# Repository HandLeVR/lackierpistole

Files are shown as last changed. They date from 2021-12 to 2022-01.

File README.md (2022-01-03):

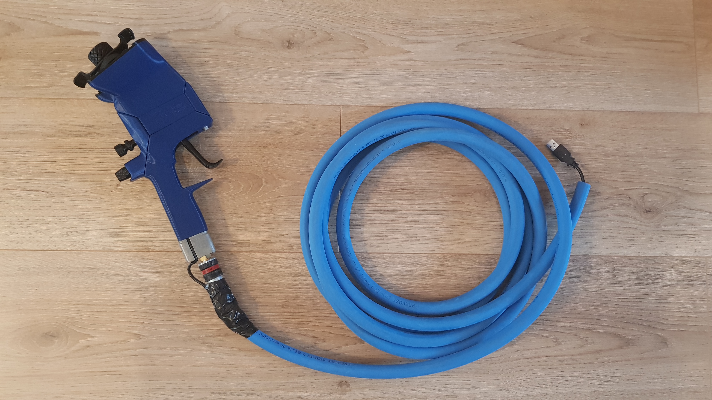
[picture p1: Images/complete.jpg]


In diesem Repository sind die 3D-Modelle sowie Anleitungen enthalten, die den Druck und den Zusammenbau einer Nachbildung einer echten Lackierpistole ermöglichen.

# Voraussetzungen
- 3D-Drucker
- Lötkolben
- Verschiedenfarbige dünne Kabel
- Schrumpfschläuche/Isolierband

Weitere benötigte Materialien sind im Dokument [BenötigteMaterialien.pdf](Anleitung/BenötigteMaterialien.pdf) aufgelistet.

# Dateistruktur

**Anleitung**: Anleitung für den Zusammenbau der Lackierpistole. Dabei wird auch beschrieben, wie die Elektronik verlötet werden muss und wie die Software auf dem Arduino Nano installiert wird.

**Druckdateien**: Die 3D-Modelle der Einzelteile der Lackierpistole, die für den Nachbau gedruckt werden müssen.

**Sketch**: Die Software, die auf dem Arduino Nano installiert werden muss.

# Druckschlauch

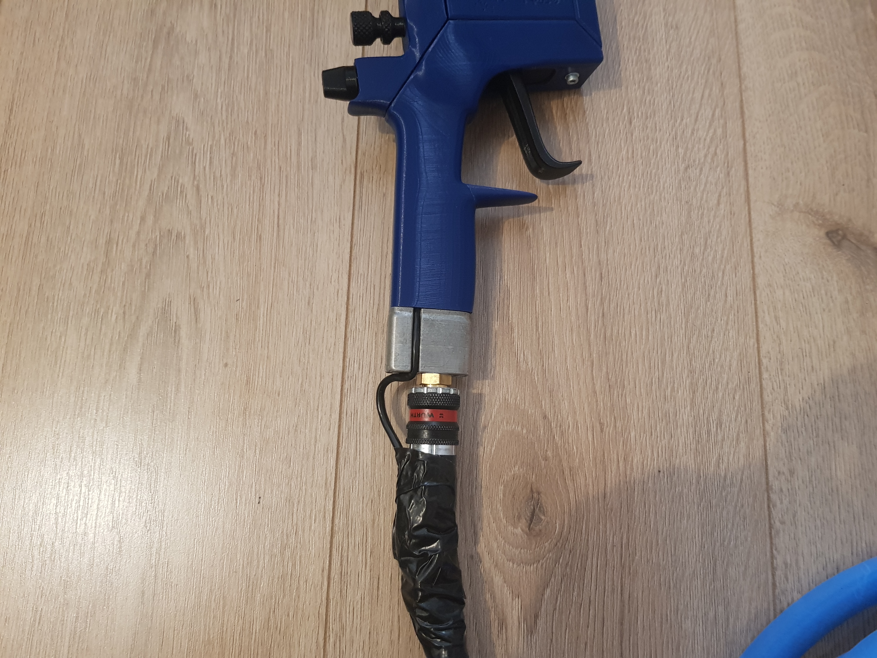
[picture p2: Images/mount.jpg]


Für eine besserer Haptik sollte ein Druckschlauch an dem Nachbau befestigt werden. Hierfür kann ein normaler Druckschlauch verwendet werden. Auf den Bildern ist ein 5 Meter langer PVC-Schlauch mit einem Innendurchmesser von 9 mm zu sehen. Soll das USB-Kabel durch den Schlauch geführt werden, sollte dieser mindestens einen Durchmesser von 9 mm haben. Zur Befestigung des Schlauches kann ein Kupplungsstecker mit Außengewinde (golden auf dem Bild) genutzt werden, der in die Druckschlauchhalterung (`Druckdateien\Druckschlauchmount\Schraubmount.3mf`) gedreht wird. Auf dem Bild ist die Druckschlauchhalterung metallisch und sollte wenn möglich auch beim eigenen Druck aus Metall bestehen.

Um das USB-Kabel durch den Schlauch zu führen, wurde dieser am Ende, das zur Lackierpistole führt, aufgeschnitten. Das Ventil am anderen Ende wurde abgeschnitten, um von hier das Kabel durch den Schlauch zu führen. In die Lackierpistole muss der USB-Mini-Stecker, weshalb dieser voran durch den Schlauch geschoben wird. In der Regel muss etwas von dem Gummi des Steckers entfernt werden, damit der Stecker durch den Schlauch passt. Der Stecker wird dann durch die aufgeschnittene Stelle am anderen Ende geführt und in die Lackierpistole gesteckt. Das schwarze Klebeband dient zur Stabilisierung.

# Treiber

Möglicherweise ist ein Treiber nötig, damit der Arduino Nano vom PC erkannt wird. Dieser kann [hier](http://www.wch-ic.com/downloads/CH341SER_ZIP.html) heruntergeladen werden.

# Lackierpistole initialisieren

Um die Lackierpistole in der VR-Lackierwerkstatt nutzen zu können, müssen die Position der Lackierpistole, der Abzugshebel und die Drehknöpfe initialisiert werden. Dies muss in der Regel nur einmal gemacht werden oder wenn sich die Position des Controllers an der Lackierpistole verändert. Der Initialisierungsprozess wird im Probiermodus der VR-Lackierwerkstatt durchgeführt. Dieser kann gestartet werden, wenn im Anmeldebildschirm *Ohne Anmeldung* oder im Hauptmenü *Probiermodus* ausgewählt wird.

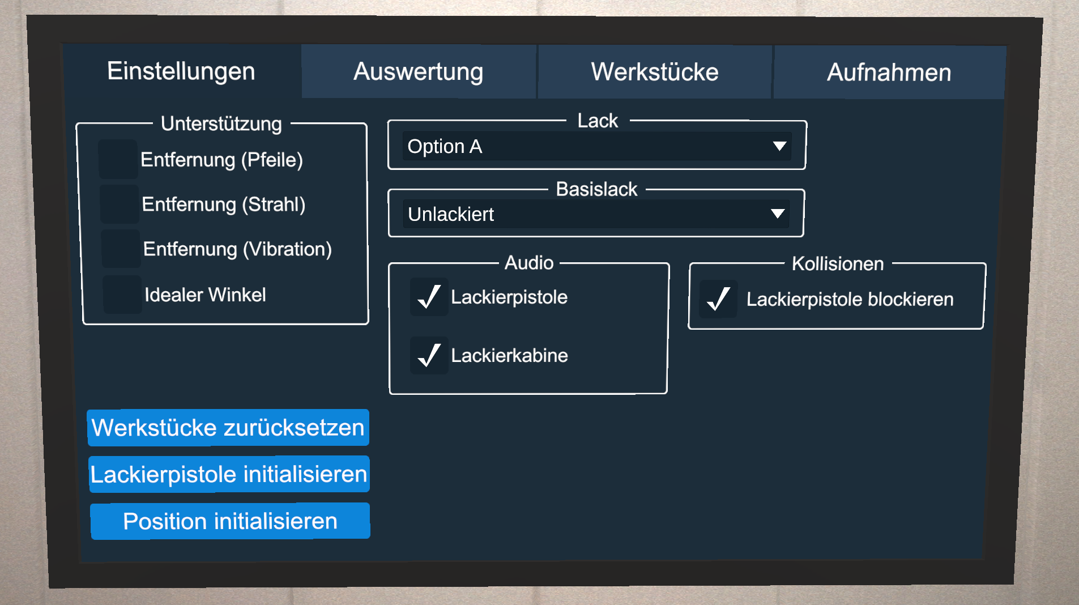
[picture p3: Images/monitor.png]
.

## Abzugshebel und Drehknöpfe initialisieren

Die Initialisierung des Abzugshebels und der Drehknöpfe kann gestartet werden, indem *Lackierpistole initialisieren* auf dem Monitor ausgewählt  oder die Taste "I" auf der Tastatur gedrückt wird. Auf dem Monitor erscheinen dann Anweisungen, die durchgeführt werden müssen.

## Position
Die Initialisierung der Position der Lackierpistole kann gestartet werden, indem *Position initialisieren* auf dem Monitor ausgewählt oder die Taste "O" auf der Tastatur gedrückt wird. Vor dem Monitor erscheint dann eine durchsichtige Lackierpistole und die virtuelle Lackierpistole in der Hand verschwindet. Nun muss die echte Lackierpistole möglichst genau so vor dem Monitor positioniert werden, dass diese mit der durchsichtigen Lackierpistole übereinstimmt. Der Prozess wird beendet, wenn der Abzughebel gedrückt wird.

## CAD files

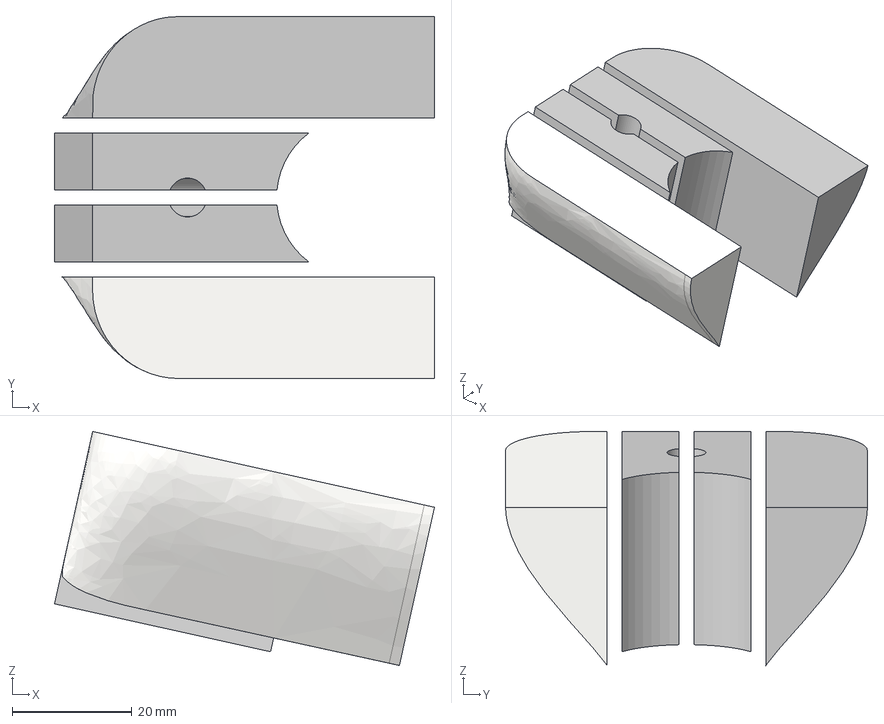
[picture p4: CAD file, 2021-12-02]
Druckdateien/Aufnahme/Gewicht.step
63.5 x 60.5 x 39.1 mm

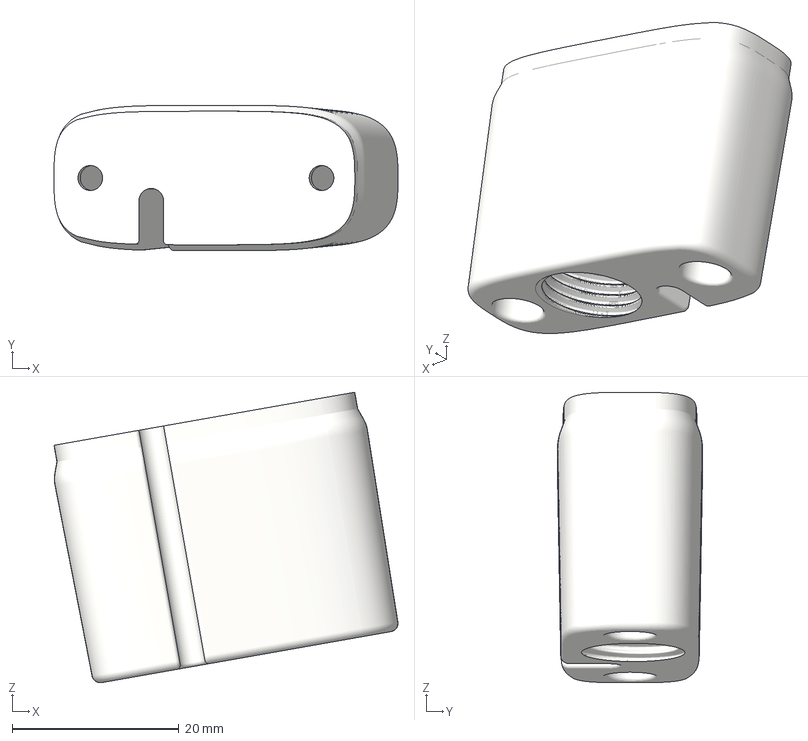
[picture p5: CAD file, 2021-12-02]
Druckdateien/Druckschlauchmount/Schraubmount.3mf
41.2 x 17.4 x 34.8 mm

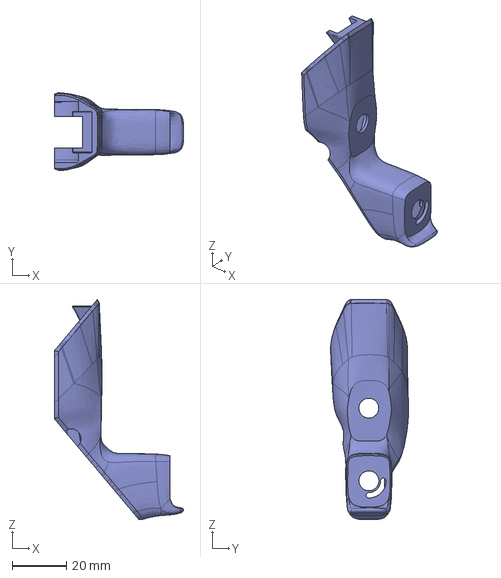
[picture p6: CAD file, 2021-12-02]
Druckdateien/Gehäuse/gehäuse hinten.step
47.6 x 28.6 x 80.9 mm

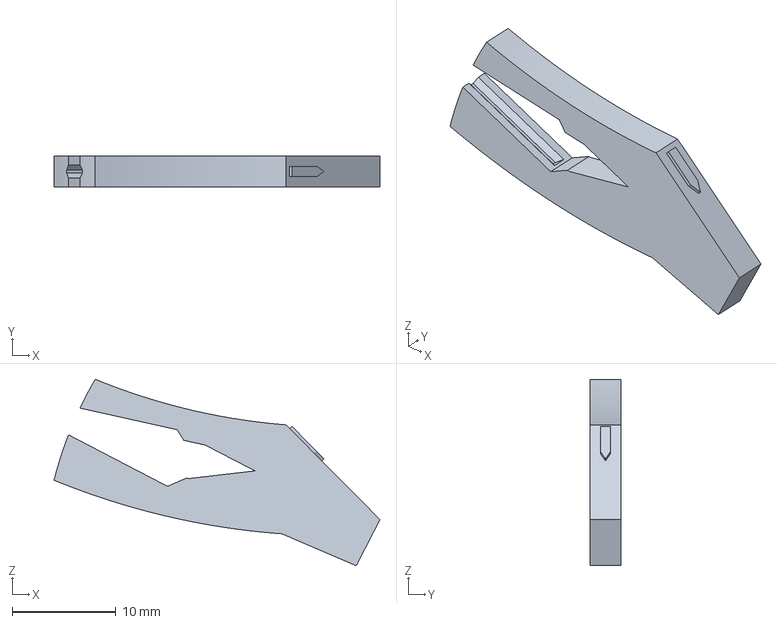
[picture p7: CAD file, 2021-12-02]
Druckdateien/Mechanik/Abzug_greifer.3mf
31.4 x 3.00 x 18.0 mm

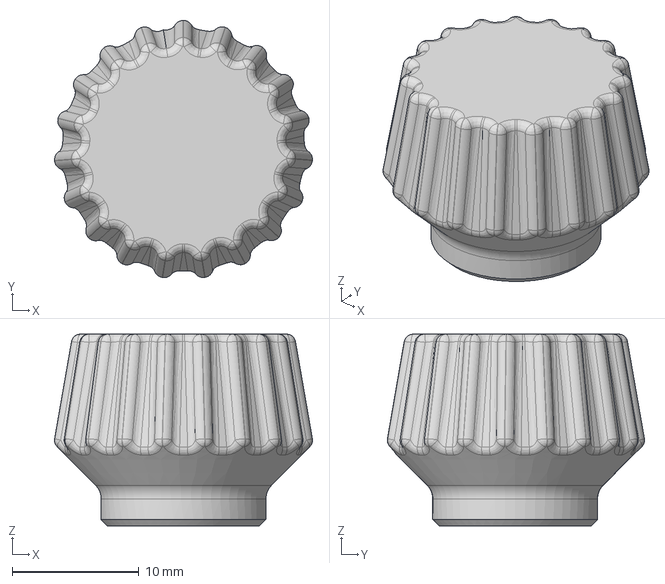
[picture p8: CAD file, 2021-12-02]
Druckdateien/Regler/Seitenregler.step
20.3 x 20.3 x 15.1 mm

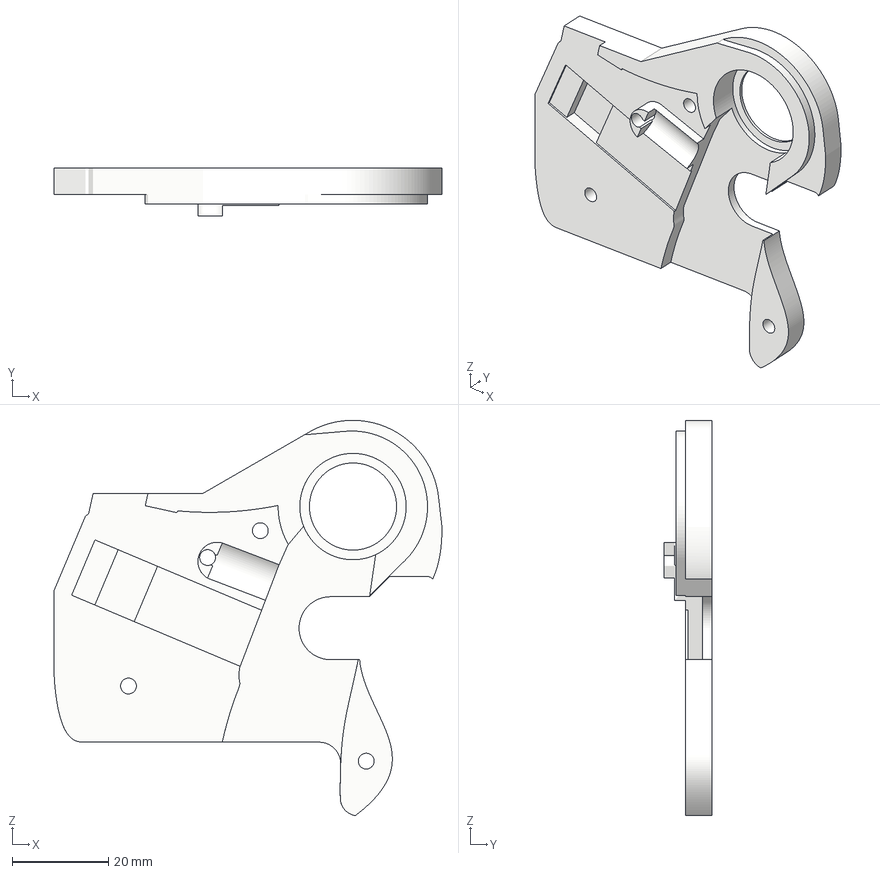
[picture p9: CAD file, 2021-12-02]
Druckdateien/Träger/Trägerkappe_rechts.3mf
80.8 x 10.0 x 82.3 mm

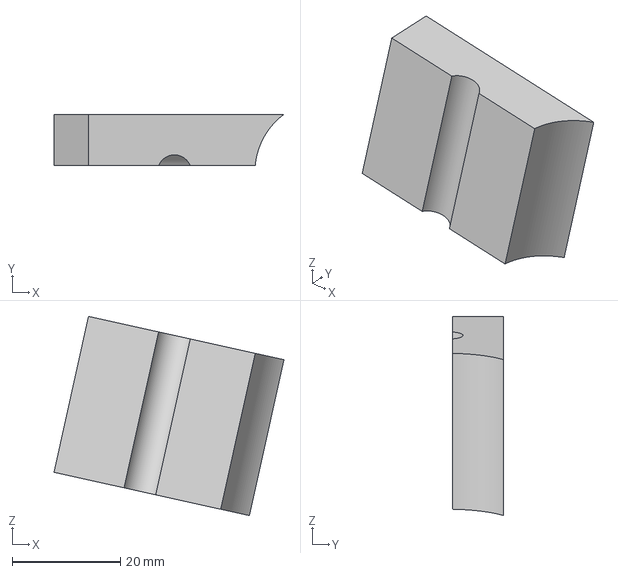
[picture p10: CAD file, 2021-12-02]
Druckdateien/Aufnahme/gewicht rr.3mf
42.5 x 9.50 x 36.8 mm

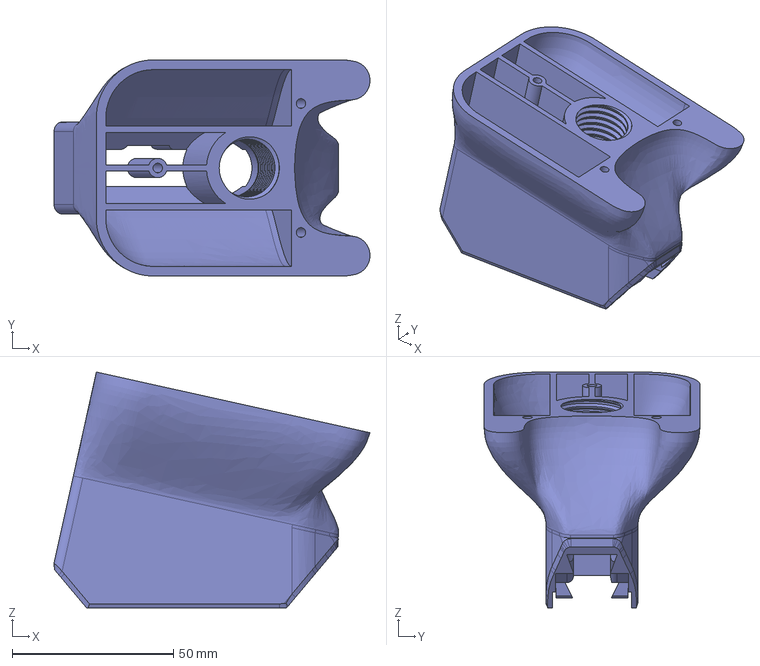
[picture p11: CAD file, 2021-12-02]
Druckdateien/Gehäuse/gehäuse oben.step
98.0 x 67.0 x 73.2 mm

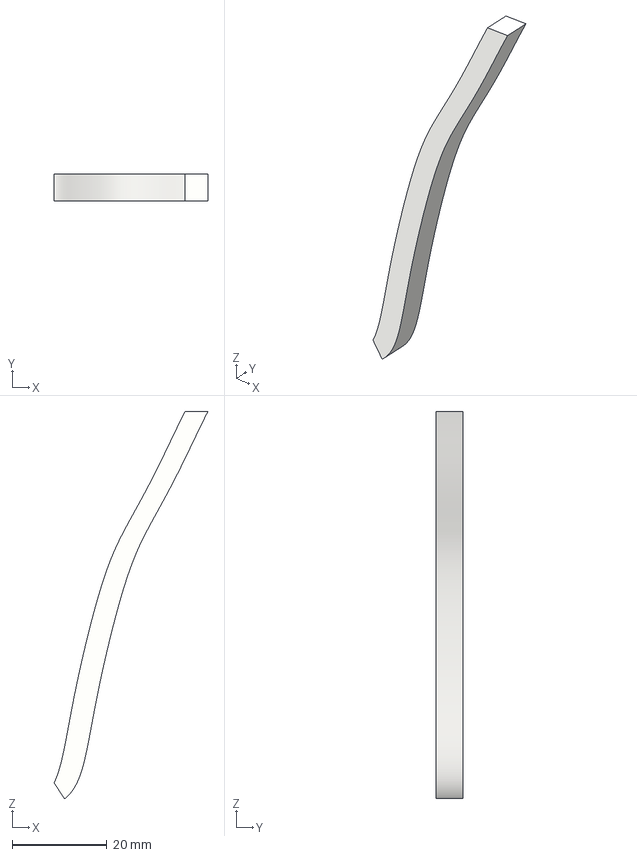
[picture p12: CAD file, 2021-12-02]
Druckdateien/Mechanik/Abzug_inlay.3mf
32.5 x 5.70 x 81.8 mm

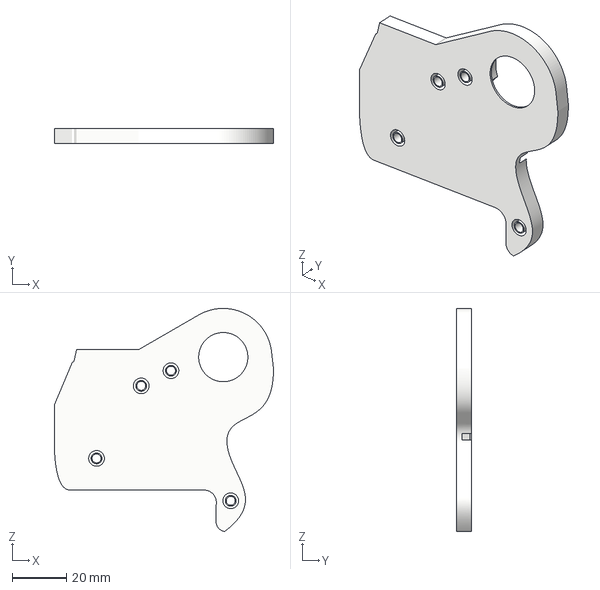
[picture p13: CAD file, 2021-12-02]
Druckdateien/Träger/Trägerkappe_links.3mf
80.8 x 5.50 x 82.3 mm

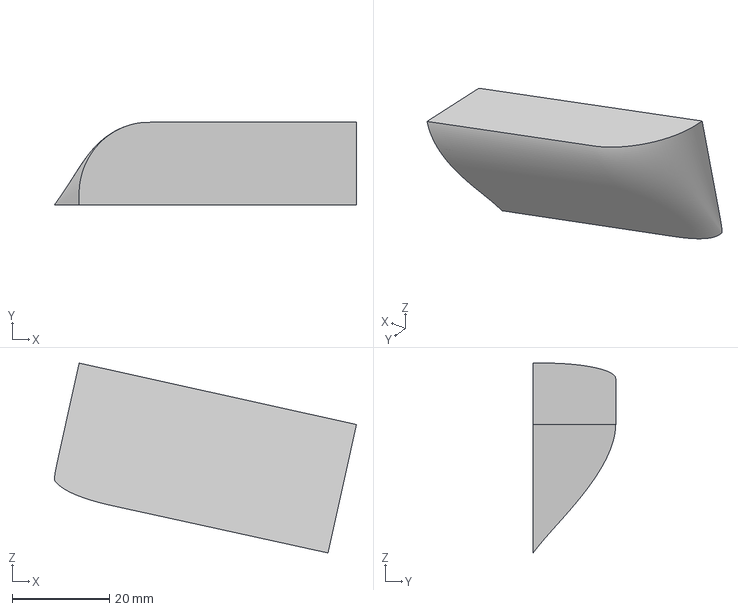
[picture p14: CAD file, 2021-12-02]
Druckdateien/Aufnahme/gewicht Rechts.3mf
62.2 x 17.0 x 39.1 mm

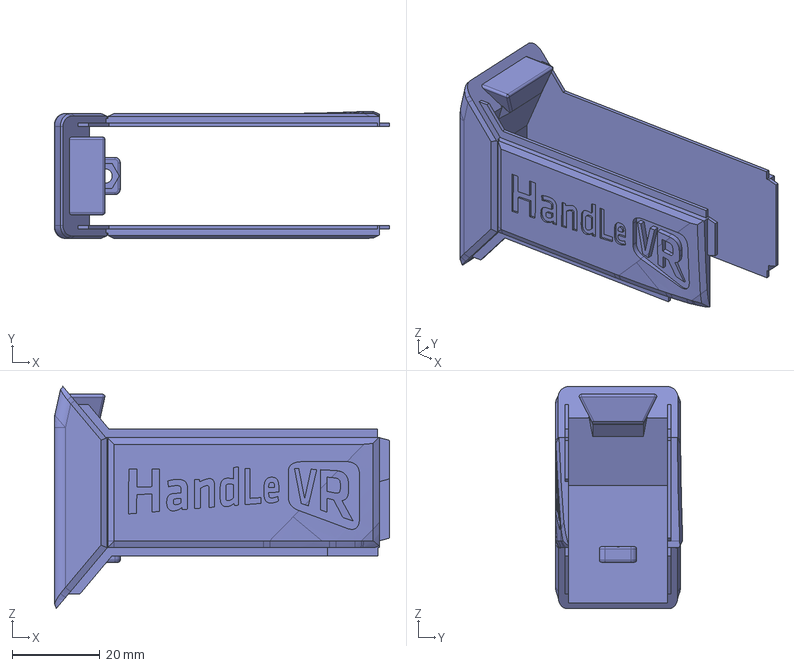
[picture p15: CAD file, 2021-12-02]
Druckdateien/Gehäuse/gehäuse vorne.step
76.4 x 28.9 x 50.6 mm

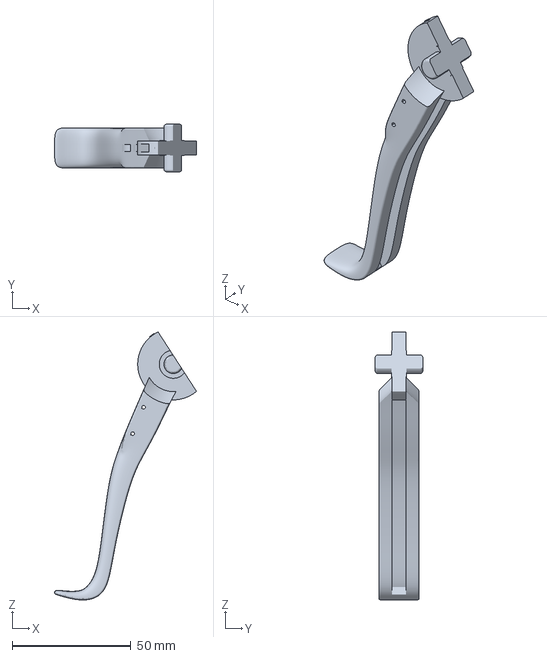
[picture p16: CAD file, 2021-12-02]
Druckdateien/Mechanik/Abzug.3mf
59.8 x 20.0 x 112.8 mm

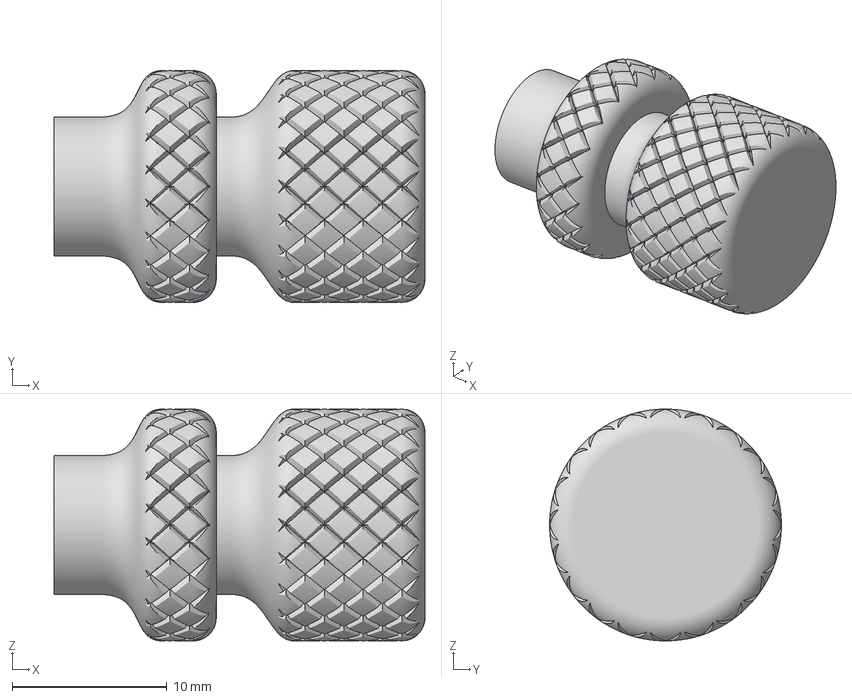
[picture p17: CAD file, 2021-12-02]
Druckdateien/Regler/Regler_HiOb.3mf
24.0 x 15.0 x 15.0 mm

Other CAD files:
Druckdateien/Druckschlauchmount/Schraubanschluss.step
Druckdateien/Regler/Regler_Seite.3mf
Druckdateien/Träger/träger.step
Druckdateien/Aufnahme/gewicht ll.3mf
Druckdateien/Aufnahme/Auflageplatte v4.step
Druckdateien/Aufnahme/Auflageplatte.3mf
Druckdateien/Aufnahme/Klemme.3mf
Druckdateien/Aufnahme/Schraube.3mf
Druckdateien/Aufnahme/Schraube.step
Druckdateien/Aufnahme/gewicht links.3mf
Druckdateien/Aufnahme/klemme v5.step
Druckdateien/Gehäuse/Gehäuse Hinten.3mf
Druckdateien/Gehäuse/Gehäuse vorne.3mf
Druckdateien/Gehäuse/Nase.3mf
Druckdateien/Gehäuse/Nasenzapfen.3mf
Druckdateien/Gehäuse/gehäuse Oben.3mf
Druckdateien/Gehäuse/gehäuse unten.step
Druckdateien/Gehäuse/gehäuse_unten.3mf
Druckdateien/Mechanik/Abzug v3.step
Druckdateien/Mechanik/Federhülse.3mf
Druckdateien/Mechanik/federhülse.step
Druckdateien/Regler/Regler_HiUn.3mf
Druckdateien/Regler/Regler_HiUn.step
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

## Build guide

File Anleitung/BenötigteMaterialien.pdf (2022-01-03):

Artikel | technische Bez. | Menge | Lospreis | Losmenge | Bemerkung
PLA | PLA | 260 g | 16,00 € | 320 g | Preislich stark optimierbar, bei uns 60€/2kg
Zinn | SN95SB4CU1 | 380 g | 27,90 € | 500 g | SN99,9/SN96AG4/… möglichst ohne Blei (Pb) -> RoHS
Kugellager | 608zz | 2 Stk | 9,99 € | 20 Stk
Feder | Z-095I | 1 Stk | 2,70 € | 1 Stk | schnell hohe Rabatte
Feder | RZ-095I | 1 Stk | 2,83 € | 1 Stk | schnell hohe Rabatte
Arduino | Arduino Nano | 1 Stk | 4,60 € | 1 Stk
Drehpotentiometer | P0915N-FC15BR10K | 3 Stk | 1,38 € | 1 Stk
Schiebepotentiometer | PTA2043-2015DPB103 | 1 Stk | 1,31 € | 1 Stk
Druckluftanschluss | NW 7,2 Stecknippel | 5 Stk | 2,00 € | 1 Stk
Schrauben für Arduino | M1x3 | 4 Stk | | | gedruckte Klemme möglich, einzeln nicht kaufbar
Schrauben | M3x16 Zylinderkopf | 5 Stk | 0,06 € | 1 Stk | Mischpreis 0,04€ bis 0,08€, oft auch als Kiloware
Schrauben | M3x25 Zylinderkopf | 1 Stk | 0,06 € | 1 Stk
Schrauben | M3x45 Zylinderkopf | 2 Stk | 0,06 € | 1 Stk
Schrauben | M3x40 Zylinderkopf | 3 Stk | 0,06 € | 1 Stk
Schrauben | M3x20 Linsenkopf | 4 Stk | 0,06 € | 1 Stk
Mutter | M3 Mutter | 6 Stk | 0,06 € | 1 Stk
Unterlegschreibe | M3 Unterlegscheibe | 3 Stk | 0,06 € | 1 Stk
Drahtnägel | 1,2 mm Druckmesser | 4 Stk

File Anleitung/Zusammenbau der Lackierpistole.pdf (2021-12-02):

Jan Philipp Seeland | November, 2019

### HandLeVR Dokumentation Zusammenbau der Sensorik im 3D Druck der Lackierpistole

Die Sensorik im inneren des Controllers sorgt dafür, dass die Bewegung am Abzug und die Position der Einstellschrauben in der HandLeVR Software rekonstruiert werden können. Grundlegende Lötkenntnisse werden für den Zusammenbau vorausgesetzt.

Zum Zusammenbau der Sensorik wird folgendes benötigt:

- Lötkolben
- 3D Modell der Lackierpistole (Kern mit Schrauben und Kugellager)
- Verschiedenfarbige dünne Kabel
- Schrumpfschläuche/Isolierband
- 3x Drehpotentiometern
- 1x Schiebepotentiometer
- 1x Arduino Nano (ohne angelötete Pins)

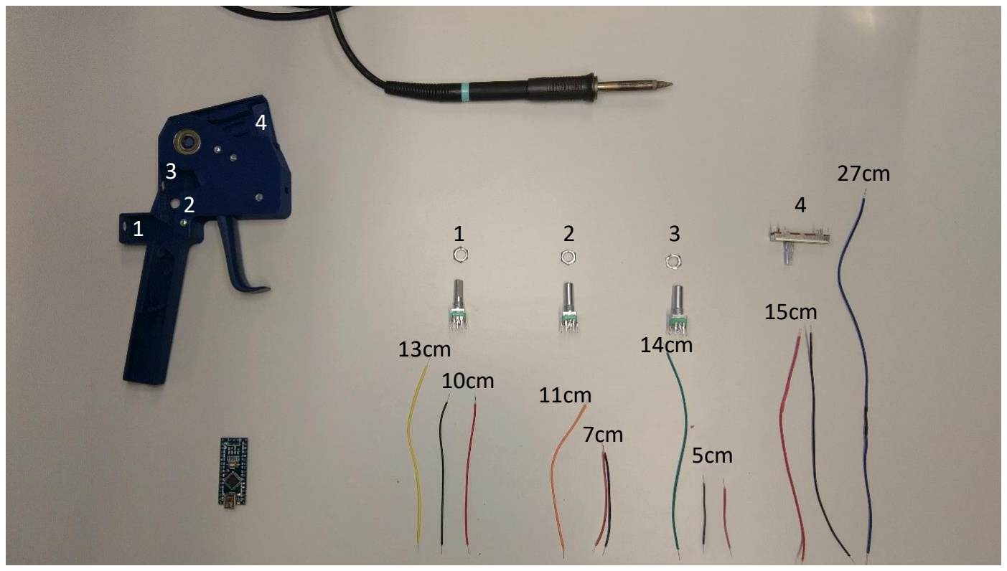
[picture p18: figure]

Die im Bild markierten Längen sind lediglich Empfehlungen! Es ist genug Stauraum im Griff der Pistole für überschüssige Kabellänge.

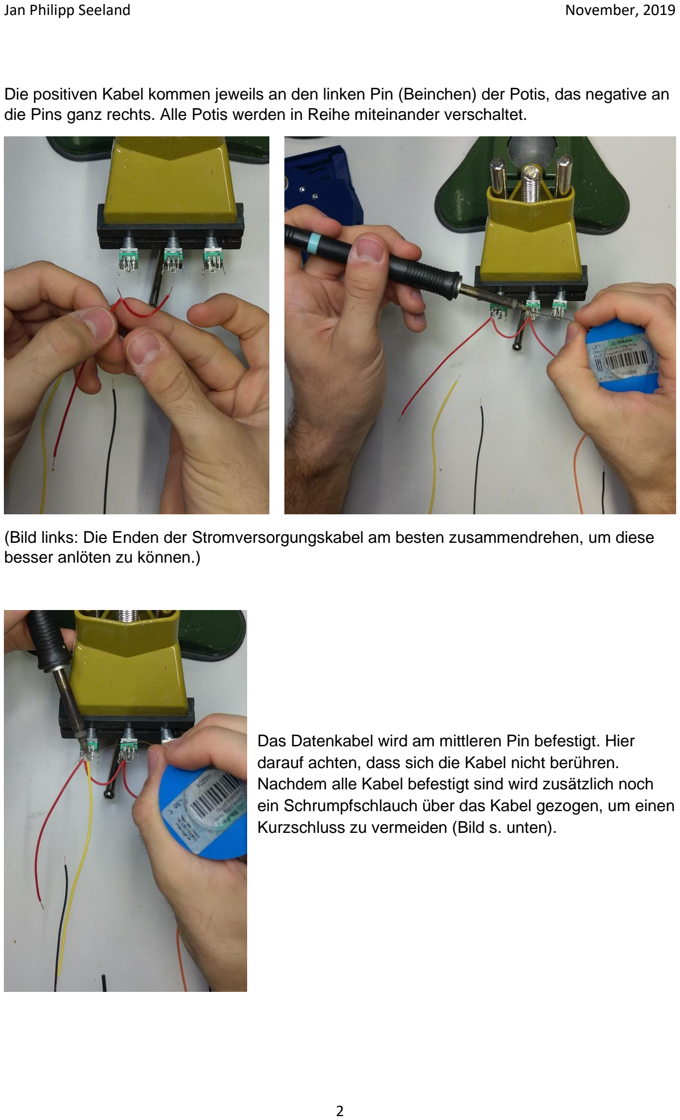
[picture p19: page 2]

Die positiven Kabel kommen jeweils an den linken Pin (Beinchen) der Potis, das negative an die Pins ganz rechts. Alle Potis werden in Reihe miteinander verschaltet.

(Bild links: Die Enden der Stromversorgungskabel am besten zusammendrehen, um diese besser anlöten zu können.)

Das Datenkabel wird am mittleren Pin befestigt. Hier darauf achten, dass sich die Kabel nicht berühren. Nachdem alle Kabel befestigt sind wird zusätzlich noch ein Schrumpfschlauch über das Kabel gezogen, um einen Kurzschluss zu vermeiden (Bild s. unten).

Beim Schiebepoti sind im Bild der Puls- und Minuspol markiert. Der nicht markierte Pin wird für die Datenleitung benutzt.
Es empfiehlt sich die Kabel nicht an die Löcher anzulöten, sondern an die jeweiligen Pins neben den Löchern, da die braune Leiterplatte nicht viel Hitze aushält und die Schleifbahnen darauf beschädigt werden könnten.

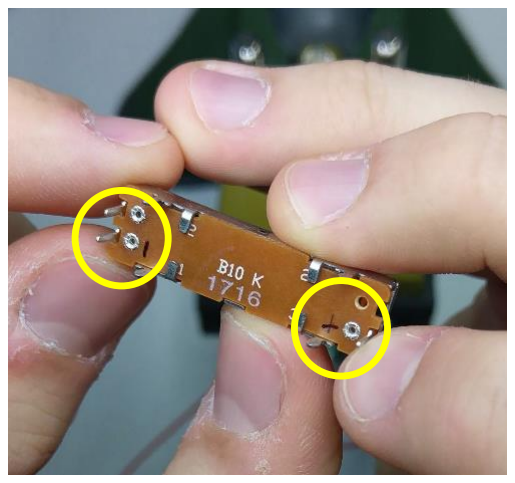
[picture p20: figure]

Wenn alle Kabel verbunden sind sollte dies in etwa so aussehen.

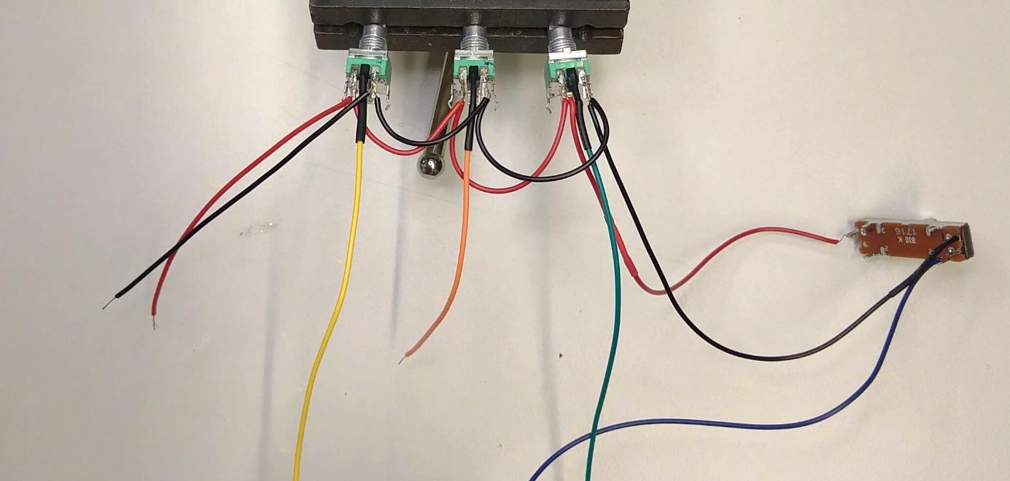
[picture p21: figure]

(Schrumpfschläuche können selbstverständlich auch über die anderen Kontakte rüber, einer in der Mitte sollte jedoch ausreichen um einen Kurzschluss auszuschließen.)

Verkabelung am Arduino:

Die Kabel müssen nun an die richtigen Aus- und Eingänge angeschlossen werden.

- 5V: positives Kabel
- GND: negatives Kabel
- A0: Poti Nr. 1
- A1: Poti Nr. 2
- A2: Poti Nr. 3
- A3: Poti Nr. 4

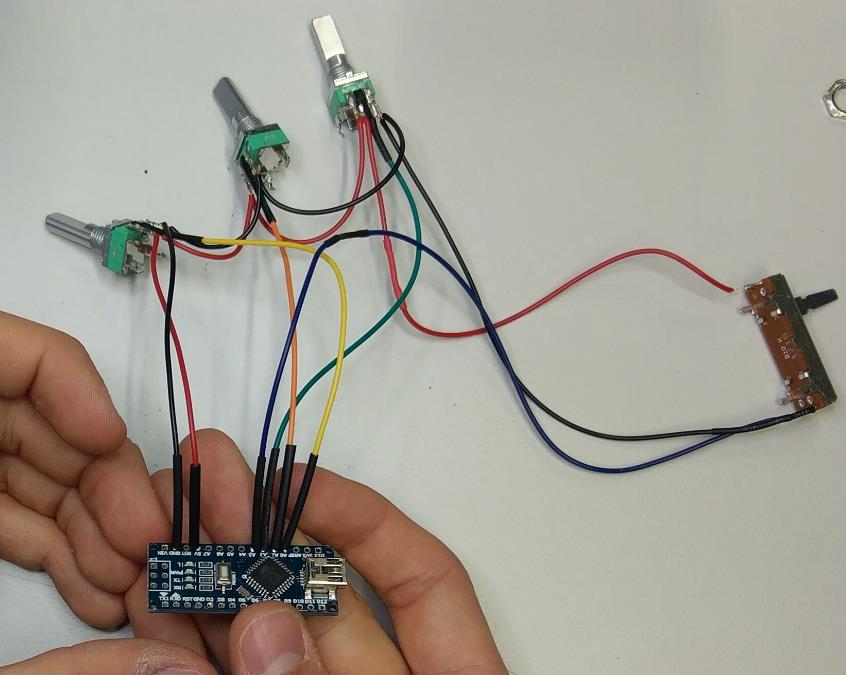
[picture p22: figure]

Da die Kontakte sehr nah aneinander liegen sollten alle Kontakte mit Schrumpfschläuchen versehen werden.

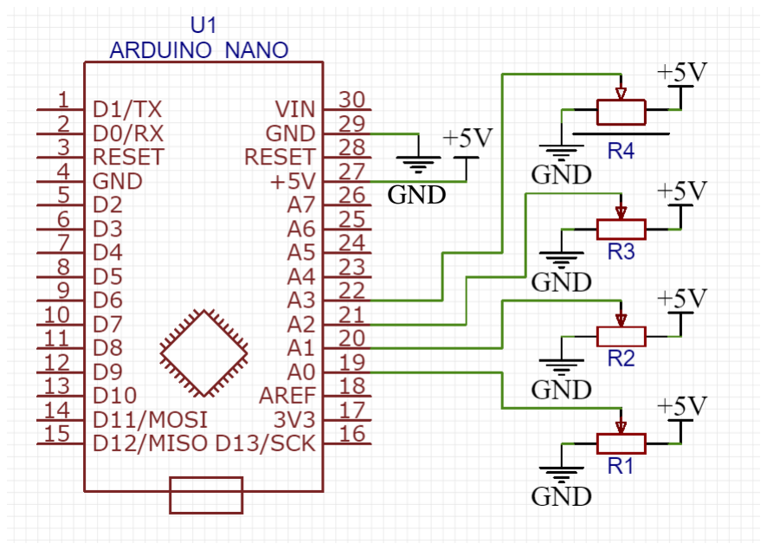
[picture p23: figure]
GND

Schematische Zeichnung zur Verkabelung.

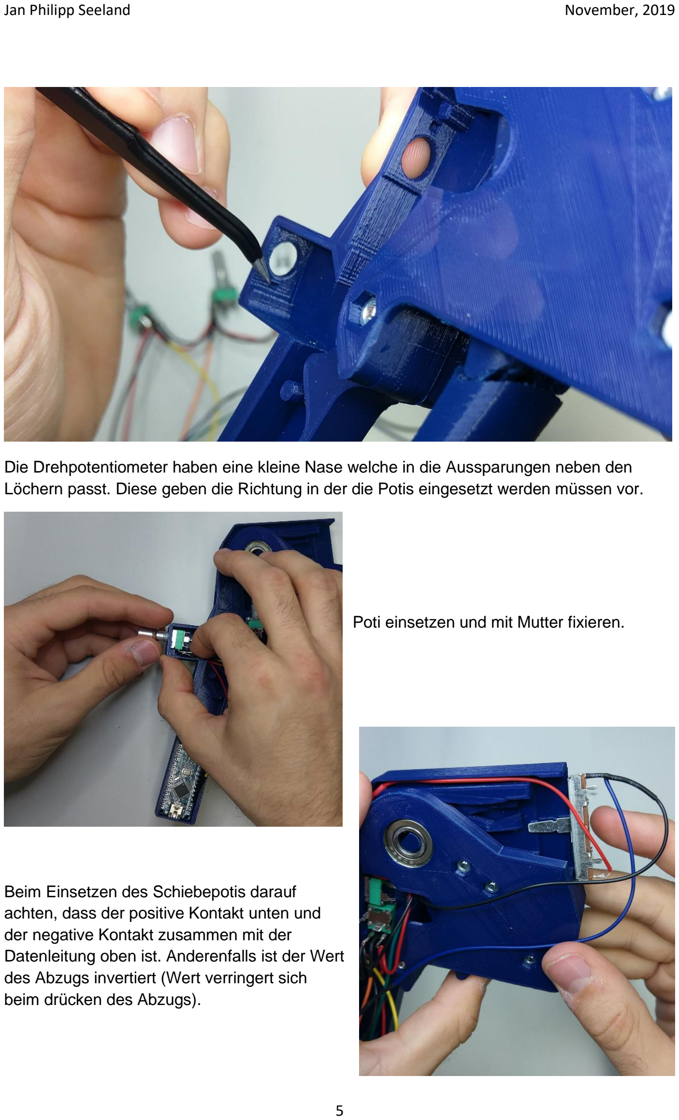
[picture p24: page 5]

Die Drehpotentiometer haben eine kleine Nase welche in die Aussparungen neben den Löchern passt. Diese geben die Richtung in der die Potis eingesetzt werden müssen vor.

Poti einsetzen und mit Mutter fixieren.

Beim Einsetzen des Schiebepotis darauf achten, dass der positive Kontakt unten und der negative Kontakt zusammen mit der Datenleitung oben ist. Anderenfalls ist der Wert des Abzugs invertiert (Wert verringert sich beim drücken des Abzugs).

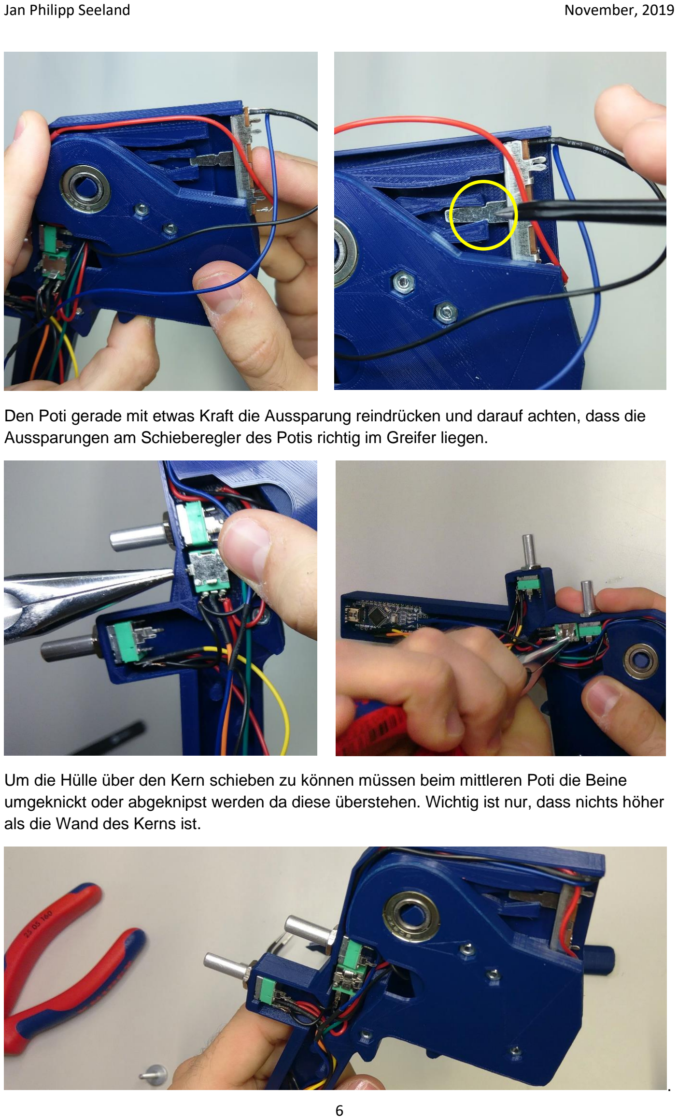
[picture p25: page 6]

Den Poti gerade mit etwas Kraft die Aussparung reindrücken und darauf achten, dass die Aussparungen am Schieberegler des Potis richtig im Greifer liegen.

Um die Hülle über den Kern schieben zu können müssen beim mittleren Poti die Beine umgeknickt oder abgeknipst werden da diese überstehen. Wichtig ist nur, dass nichts höher als die Wand des Kerns ist.

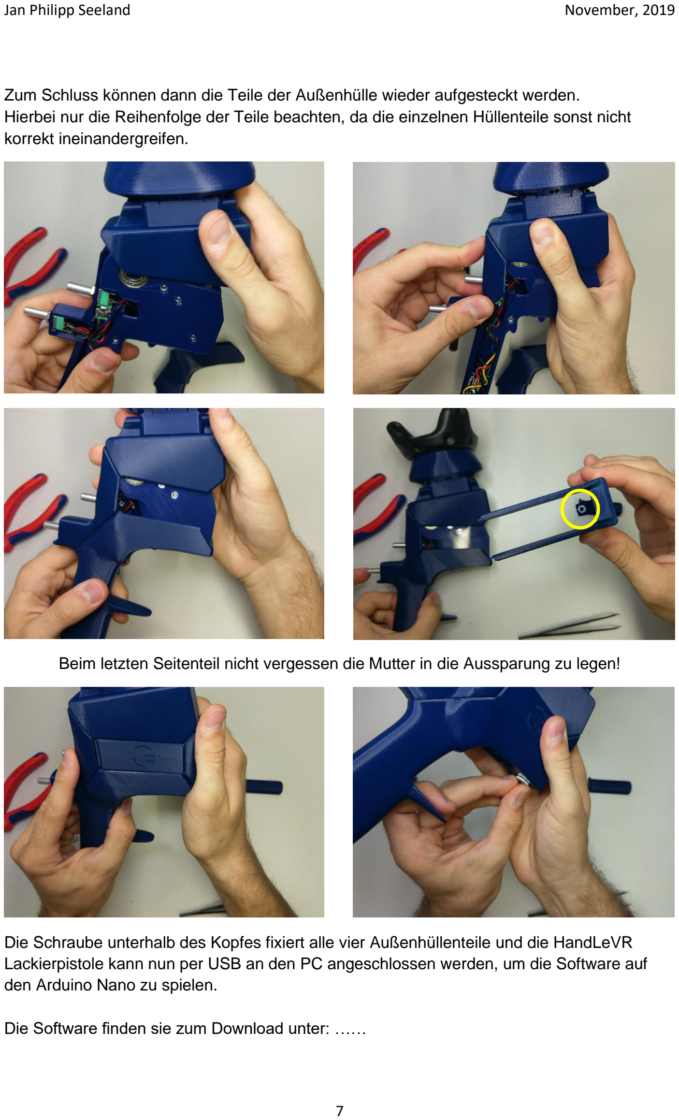
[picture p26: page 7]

Zum Schluss können dann die Teile der Außenhülle wieder aufgesteckt werden. Hierbei nur die Reihenfolge der Teile beachten, da die einzelnen Hüllenteile sonst nicht korrekt ineinandergreifen.

Beim letzten Seitenteil nicht vergessen die Mutter in die Aussparung zu legen!

Die Schraube unterhalb des Kopfes fixiert alle vier Außenhüllenteile und die HandLeVR Lackierpistole kann nun per USB an den PC angeschlossen werden, um die Software auf den Arduino Nano zu spielen.

Die Software finden sie zum Download unter: ……

Um die Software auf den Microcontroller zu flashen benötigen Sie die „Arduino IDE“.
Diese finden sie auf der offiziellen Internetseite von Arduino zum Download: https://www.arduino.cc/en/Main/Software
Nachdem die Software heruntergeladen und installiert ist, können Sie die IDE öffnen und die Pistole über USB an den Rechner anschließen.
Das heruntergeladene Programm kann ebenfalls in der IDE geöffnet werden.

Wenn alles korrekt angeschlossen ist und funktioniert dann steht oben in der Menu Leiste unter

Werkzeuge -> Port: „COM X“

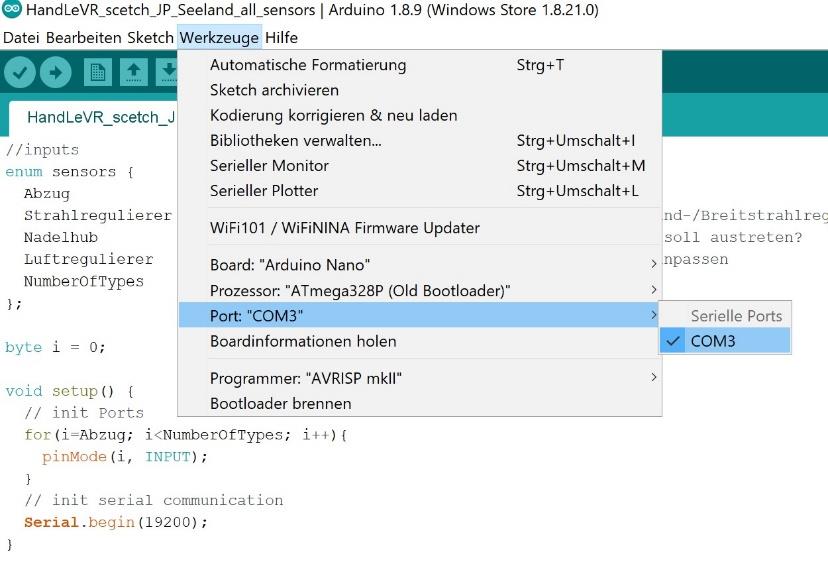
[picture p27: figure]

wobei X eine Zahl ist, die je nach PC unterschiedlich sein kann, je nachdem welcher COM Port dem Arduino zugeordnet wurde. Stellen Sie sicher, dass dieser ausgewählt ist.

Gehen sie weiter unter Werkzeuge zum Punkt „Board“. Unter diesem Punkt muss „Arduino Nano“ ausgewählt werden.

Werkzeuge -> Board
-> Arduino Nano

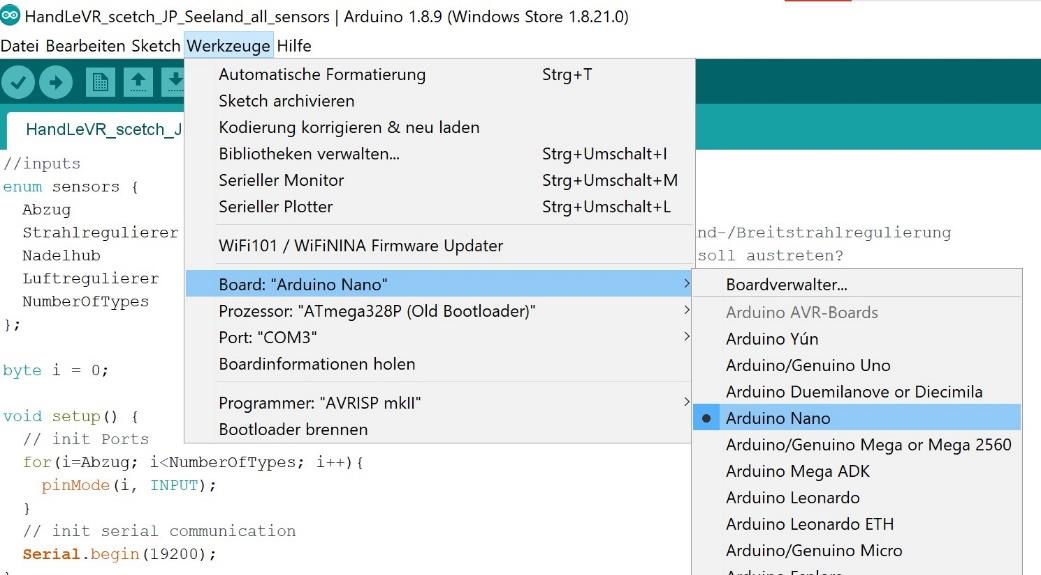
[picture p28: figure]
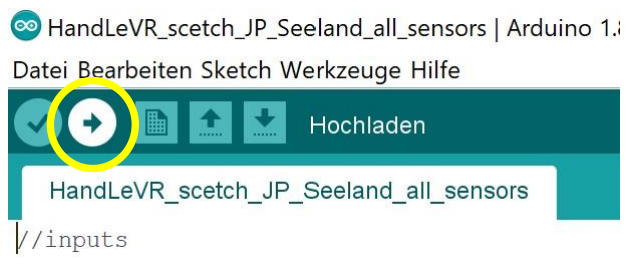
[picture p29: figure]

Jetzt kann das Programm kompiliert und übertragen werden. Dazu oben links im Programm auf den Pfeil rechts neben dem Haken klicken.

Wenn keine Fehler aufgetreten sind wird folgende Meldung in der Konsole ausgegeben:

Tritt anstelle der oberen Meldung folgender Fehlermeldung auf,

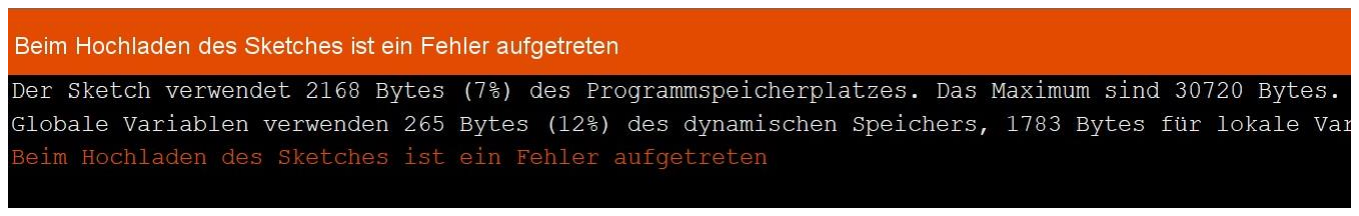
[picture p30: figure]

benutzt der Arduino einen anderen als den vorausgewählten Bootloader. Standardmäßig ist der „ATmega328P“ Bootloader ausgewählt. Unter Werkzeuge -> Prozessor kann dieser umgestellt werden. Dort den „ATmega328P (Old Bootloader)“ auswählen. Danach sollte die gleiche Erfolgsmeldung wie oben ausgegeben werden, nachdem der Pfeil zum erneuten Kompilieren gedrückt wurde.

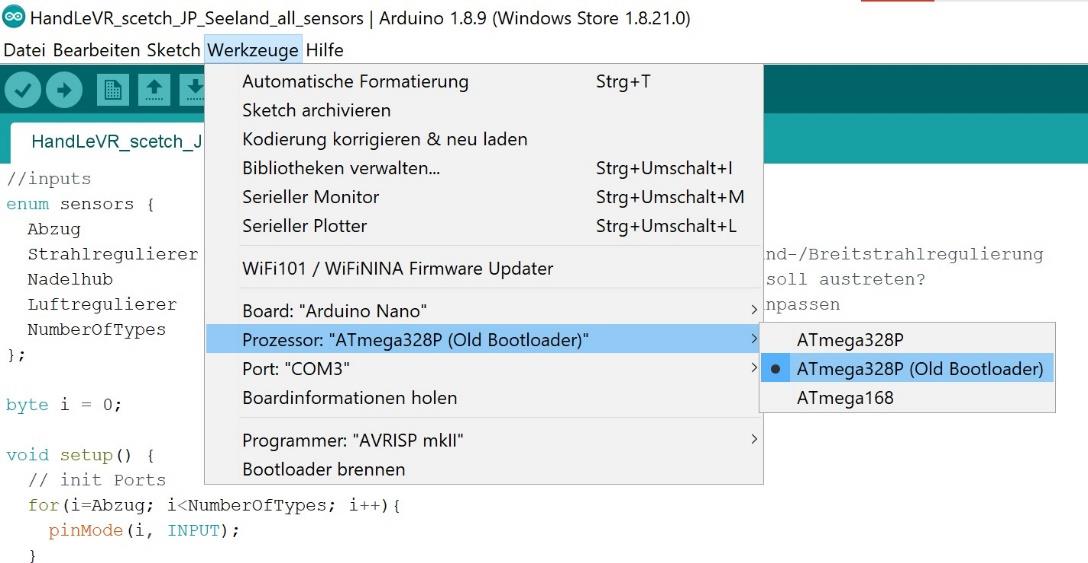
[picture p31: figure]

Werkzeuge -> Prozessor -> ATmega328 (Old Bootloader)

Zum Schluss kann noch unter Werkzeuge über den Seriellen Monitor getestet werden ob der Microkontroller korrekt arbeitet.

Werkzeuge -> Serieller
Monitor

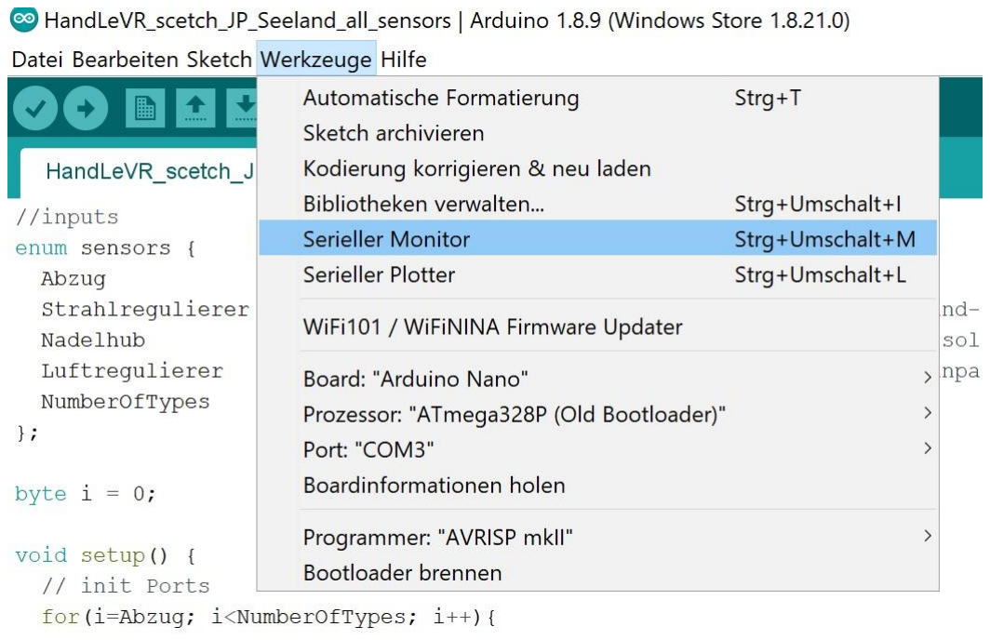
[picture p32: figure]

Baud Rate auf 19200 stellen, oben in Eingabeleiste „v“ eingeben.

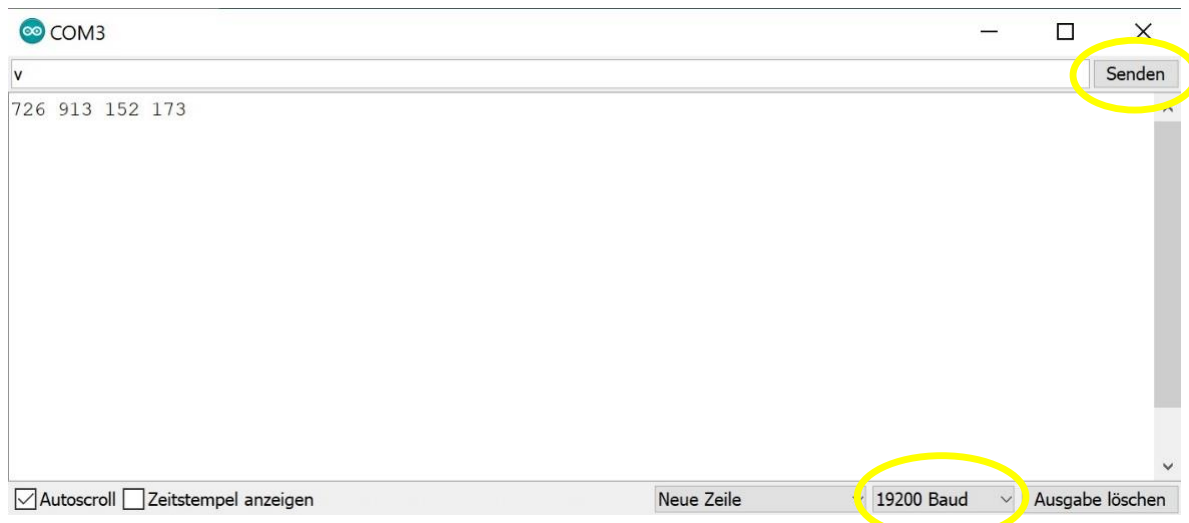
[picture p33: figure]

Wenn nun wie auf dem Screenshot 4 verschiedene Werte erscheinen funktioniert alles korrekt.

Damit kann die HandLeVR Lackierpistole in der VR Umgebung kalibriert und verwendet werden.

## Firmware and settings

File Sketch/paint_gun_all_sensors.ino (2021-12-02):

//inputs
enum sensors {
  Abzug            =  A0, //der Abzug halt, selbsterklärend...
  Strahlregulierer =  A1, //Stellschraube an der Seite -> Einst. für Rund-/Breitstrahlregulierung
  Nadelhub         =  A2, //Stellschraube hinten oben -> Wieviel Farbe soll austreten?
  Luftregulierer   =  A3, //Stellschraube hinten unten -> Luftvolumen anpassen
  NumberOfTypes
};

byte i = 0;

void setup() {
  // init Ports
  for(i=Abzug; i<NumberOfTypes; i++){
    pinMode(i, INPUT);
  }
  // init serial communication
  Serial.begin(19200);
}

byte j = 0;
char input;
#define avg_sample_count 6
long data[NumberOfTypes] = {0};
bool stopSerialPrint = 0;

void loop() {
  //read input
  input = Serial.read();
  //sample data
  for(i = Abzug; i < NumberOfTypes; i++){
      //clear old data
      data[i] = 0;
    for(j = 0; j < avg_sample_count; j++){
      //get 6 samples
      data[i] += analogRead(i);
    }
    //send avg if key input received
    if(input == 'v'){
      Serial.print(data[i]/avg_sample_count); 
      Serial.print(" ");
    }
  }
  if(input == 'v'){
    Serial.println();
  }
}
